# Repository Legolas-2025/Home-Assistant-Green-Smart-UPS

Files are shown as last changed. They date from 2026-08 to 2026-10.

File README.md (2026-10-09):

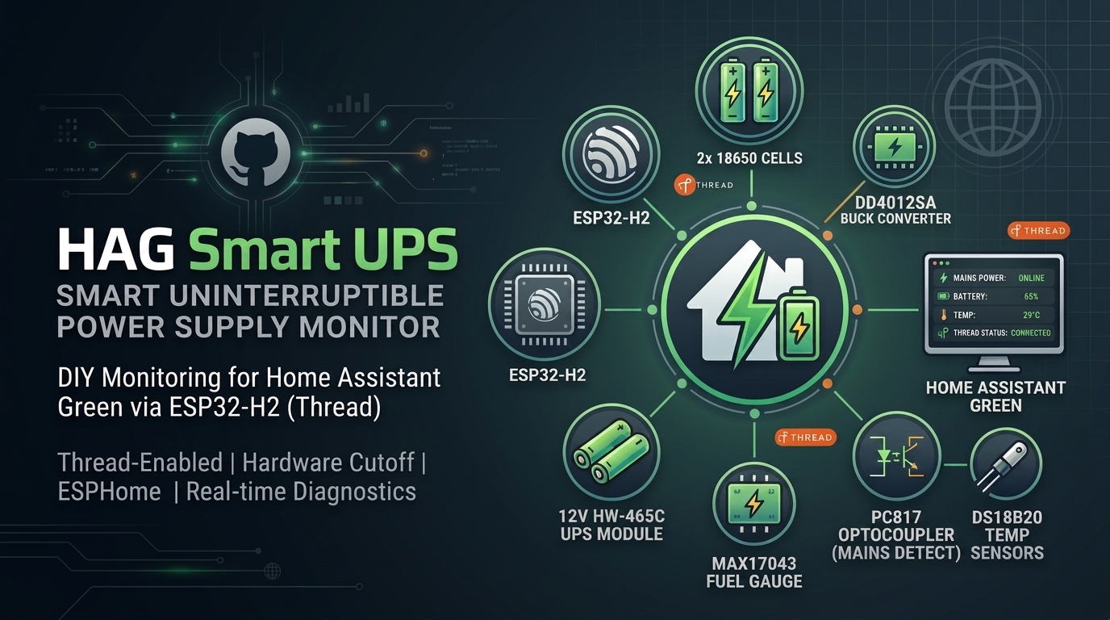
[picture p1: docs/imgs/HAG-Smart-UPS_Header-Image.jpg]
HAG Smart UPS


# Home Assistant Green Smart UPS - *Up To 5.5 Hours Runtime*

> A DIY Uninterruptible Power Supply with smart monitoring capabilities for the Home Assistant Green hub, featuring ESP32-H2 microcontroller and Thread wireless protocol.

## What's New in v1.2.1-alpha

**Changed — polling behaviour**
- **The Thread diagnostics were polling far faster than documented.** `openthread_info` defaults are aggressive:
  `parent_last_rssi` polls every **5 s**, and `role` / `ip_address` / `channel` every **1 s**. Those four
  entities alone accounted for roughly **11,500 messages per hour** over the Thread link — by a wide margin
  the largest source of traffic on this device, and far bigger than the sensor polling discussed below. They are
  now set to **900 s**.
- **The timestamp and status text sensors no longer self-poll.** They previously re-sent identical strings every
  60 s on top of being published explicitly by the mains-detection handlers. They now use
  `update_interval: never`, with the restored NVS values published once at boot.

**Added**
- **Delta filters on the battery and temperature sensors.** Readings are still taken on every poll but are only
  *transmitted* when they actually change — see [Sensor Update Intervals](#sensor-update-intervals).
- **`update_interval` now also governs both DS18B20 cell sensors**, so lowering the slider speeds up
  thermal-fault detection as well. Range widened from 10–120 s to **10–300 s**.

> Note when editing the YAML: `update_interval` must be placed **inside** each `openthread_info` entity key
> (`parent_last_rssi: { name: ..., update_interval: ... }`). At platform level it fails validation with
> `[update_interval] is an invalid option for [sensor.openthread_info]`.

---

## What's New in v1.2.0-alpha

> ⚠️ **Read this before upgrading from v1.1a** — your event timestamps were being recorded against the
> **wrong edge** of the mains-detection signal.

**Fixed**
- **Mains detection triggers were inverted.** The outage timestamp was written when power *arrived* and the
  restore timestamp when power *left*. Because the PC817 pulls GPIO4 LOW while mains is present and
  `inverted: true` maps LOW → ON, `on_press` is **mains restored** and `on_release` is **mains lost**.
  Both handlers are now swapped. This also resets the `low_bat_logged` flag at the correct moment, so the
  3 % critical event logs reliably on each subsequent outage.
- **Restore timestamps could be written as `1970-01-01`.** The mains-restored handler formatted the clock
  without checking `is_valid()`, so an unsynced clock produced a bogus epoch timestamp. It now reports
  `Time Sync Pending`, matching the outage handler.

**Added**
- **The *Sensor Update Interval* control now works.** It was declared but never read by any component — a
  dead entity advertised in the README. It now drives the MAX17043 polling loop at runtime and re-applies
  the stored value after a reboot.
- **`safe_mode` boot-loop guard**, tuned against the documented "Boot Loop on Power Restore" issue.
- Documented minimum ESPHome versions and the reason each one matters.

**Corrected in documentation** — runtime title now matches the 5–5.5 h calculation; the `tlv:` key is
documented as correct (see below); power pins are all on the top-right; the sample Thread dataset is now
valid hex; OVP removed from the DD4012SA protection list; "survives reboot" claims corrected.

> 🔒 **Do not "fix" `openthread: tlv:` into `network_dataset:`.** There is no such option — ESPHome fails
> to compile with `[network_dataset] is an invalid option for [openthread]`.

---

## Table of Contents
- [What's New in v1.2.1-alpha](#whats-new-in-v121-alpha)
- [What's New in v1.2.0-alpha](#whats-new-in-v120-alpha)
1. [Overview](#overview)
2. [Features](#features)
3. [Bill of Materials](#bill-of-materials)
4. [Power and Connection Diagram](#power-and-connection-diagram)
5. [Step-by-Step Assembly Guide](#step-by-step-assembly-guide)
6. [ESP32-H2 Super Mini Pinout Reference](#esp32-h2-super-mini-pinout-reference)
7. [Software Configuration](#software-configuration)
8. [Thread Network Setup](#thread-network-setup)
9. [Estimated Runtime](#estimated-runtime)
10. [Troubleshooting](#troubleshooting)
11. [Future Modifications](#future-modifications)

---

## Overview

This project provides a complete DIY Uninterruptible Power Supply (UPS) system with smart monitoring capabilities for the Home Assistant Green hub. The system utilizes:

- **ESP32-H2 Microcontroller**: Wireless communication via Thread protocol
- **HW-465C UPS Module**: 12V boost conversion and battery charging management
- **MAX17043 Fuel Gauge**: Real-time battery state of charge monitoring
- **DS18B20 Temperature Sensors**: Battery cell temperature monitoring
- **PC817 Optocoupler**: Mains power detection
- **DD4012SA Buck Converter**: 12V to 5V step-down conversion with built-in protections

The "Hardware Cutoff" configuration ensures the Home Assistant Green automatically reboots when grid power is restored, without requiring software-managed relays.

---

## Features

| Feature | Description |
|---|---|
| **Real-time Monitoring** | Battery level, voltage, cell temperatures, mains status |
| **Thread Protocol** | Wireless communication via OpenThread Border Router |
| **Persistent Logging** | NVS-backed timestamps that survive power loss |
| **Smart Time Sync** | Auto-retry mechanism (up to 4.5 minutes) |
| **Remote Management** | Restart button and adjustable polling interval |
| **Hardware Protection** | Automatic battery cutoff to prevent deep discharge |
| **Protected Power Path** | DD4012SA provides built-in UVLO/OCP/SCP/OTP for the ESP32 rail |

---

## Home Assistant Integration

Once flashed and connected to your Thread network, the HAG Smart UPS automatically integrates with Home Assistant, exposing a comprehensive set of entities for monitoring and control.

### Exposed Sensors

| Entity Name | Type | Description | Polled Every | Sent To HA When |
|---|---|---|---|---|
| **UPS Battery Level** | Percentage | Real-time state of charge from MAX17043 fuel gauge | 30s (slider 10-300s) | level moves ≥ 1 % |
| **UPS Battery Voltage** | Voltage (V) | Current battery voltage (3.0V - 4.2V range) | 30s (slider 10-300s) | moves ≥ 0.05 V |
| **UPS Battery Cell 1 Temperature** | Temperature (°C) | DS18B20 temperature reading on cell 1 | 30s (slider 10-300s) | moves ≥ 0.5 °C |
| **UPS Battery Cell 2 Temperature** | Temperature (°C) | DS18B20 temperature reading on cell 2 | 30s (slider 10-300s) | moves ≥ 0.5 °C |
| **UPS Thread Signal Strength** | RSSI (dBm) | Thread network signal strength to OTBR | 900s | every poll |

### Exposed Binary Sensors

| Entity Name | Type | Description |
|---|---|---|
| **Mains Power Status** | Binary | ON when grid power is present, OFF during outage |

### Exposed Text Sensors (Event Logging)

| Entity Name | Description | Persistence |
|---|---|---|
| **Time Sync** | Current time synchronization status (Pending/Success/Failed) | Resets on reboot |
| **Last Power Outage Time** | Timestamp when last mains failure was detected | Survives reboot |
| **Last Mains Restore Time** | Timestamp when mains power was restored | Survives reboot |
| **Last Low Battery 3% Time** | Timestamp when critical 3% battery threshold was reached during outage | Survives reboot |
| **Last Reboot Time** | Timestamp of last ESP32-H2 boot | Resets on reboot |

### Exposed Thread Network Info

| Entity Name | Description |
|---|---|
| **Thread Device Role** | Current OpenThread device role (Child/Sleepy End Device) |
| **Thread IP Address** | Assigned IPv6 address on the Thread network |
| **Thread Channel** | Thread radio channel in use |

### Exposed Buttons

| Entity Name | Action |
|---|---|
| **Restart UPS Monitor** | Triggers a soft restart of the ESP32-H2 firmware |

### Exposed Controls

| Entity Name | Range | Default | Description |
|---|---|---|---|
| **Sensor Update Interval** | 10s - 300s (10s steps) | 30s | Polling interval for the fuel gauge **and both cell temperature sensors** (live as of v1.2.0-alpha, extended in v1.2.1-alpha) |

---

## What You Get

Building this project gives you a complete, self-contained UPS monitoring solution for your Home Assistant Green hub:

**Core Functionality:**
- **Intelligent Battery Management**: The MAX17043 fuel gauge provides accurate state-of-charge readings, while the dual DS18B20 sensors monitor cell temperatures to prevent thermal runaway
- **Power Outage Detection**: Instant notification when mains power is lost, with automatic timestamp logging of outage start, end, and critical events
- **Automatic Recovery**: The "Hardware Cutoff" design ensures your Home Assistant Green reboots automatically when power is restored—no software intervention needed
- **Extended Runtime**: Up to 5.5 hours of backup power with dual 18650 cells in 1S2P configuration

**Smart Monitoring Features:**
- Persistent event logging that survives power cycles and reboots
- Smart time synchronization with automatic retry logic
- Configurable update intervals for battery polling
- Thread network diagnostics (signal strength, device role, IP address)

**Integration Benefits:**
- All entities appear automatically in Home Assistant via the native ESPHome API
- Build automations around power events (e.g., notify when outage begins, log battery levels)
- Remote device management with one-click restart capability
- No cloud dependencies—everything runs locally on your network

---

## Bill of Materials

### Core Components

| Component | Quantity | Notes |
|---|---|---|
| Home Assistant Green | 1 | Main hub (Load) |
| ESP32-H2 Super Mini | 1 | Thread end device |
| SLZB-MR5U (or similar) | 1 | OpenThread Border Router |
| HW-465C UPS Module | 1 | 12V boost + charger |
| 18650 Battery Cells | 2 | 3000mAh+ capacity, 1S2P configuration |
| MAX17043 I2C Fuel Gauge Module | 1 | Battery SoC monitoring |
| PC817 or EL817 Optocoupler | 1 | Mains detection (drop-in replacement — verify CTR if detection is unreliable) |
| DS18B20 Temperature Sensors | 2 | One per battery cell |
| DD4012SA Buck Converter (5V variant) | 1 | 12V to 5V conversion with built-in protections |

### Electronic Components

| Component | Value | Notes |
|---|---|---|
| Current-limiting Resistor (Optocoupler LED) | 330Ω | For optocoupler input |
| Pull-up Resistor (1-Wire Bus) | 4.7kΩ | For DS18B20 data line |
| Electrolytic Capacitor (Optional) | 100µF - 220µF | Voltage stabilization on the 5V rail |

### Power Supply Requirements

| Parameter | Specification | Notes |
|---|---|---|
| Input Voltage | 220V AC (Mains) | Standard household outlet |
| Output Voltage | 5V DC | USB-C connector |
| Output Current | 3.6A+ / 18W+ | Required for simultaneous charging and operation |
| Connector Type | USB-C | Must use "dumb" charger (no PD/PPS) |

> ⚠️ **IMPORTANT**: Do NOT use fast chargers with PD, PPS, or QuickCharge protocols. The HW-465C lacks smart negotiation chips, and these chargers will default to 5V/1A-2A, causing insufficient power supply.

### Cables and Connectors

| Item | Specification |
|---|---|
| DC Output Cable | 12V, male 5.5x2.1mm center-positive |
| Jumper Wires | Various lengths for prototyping |
| Breadboard/Prototype Board | For circuit assembly |

---

## DD4012SA Buck Converter - Detailed Specifications

The DD4012SA is a compact, industrial-grade 5W DC-DC step-down buck converter. The output voltage is **factory-set by SKU** (no potentiometer adjustment required), eliminating the risk of accidental over-voltage that can permanently damage the ESP32-H2.

### DD4012SA Configuration (5V Variant)

| Parameter | Value | Notes |
|---|---|---|
| Module Variant | DD4012SA_5V | Order specifically the 5V output version |
| Input Voltage | 6.5V – 40V DC | Range comfortably covers the 12V HW-465C rail |
| Output Voltage | 5.0V DC | Factory preset, no user adjustment required |
| Max Output Current | 1A | More than sufficient for the ESP32-H2 (~100 mA peak) |
| Quiescent Current | ~1.5 mA | Very low idle draw, battery-friendly |
| Efficiency | 76% – 90% | Depends on load and input voltage |
| Switching Frequency | 550 kHz | Fixed |
| Pin Pitch | 2.54 mm | Breadboard / Arduino-friendly |
| Form Factor | TO-220 compatible | Can drop-in replace LM78XX linear regulators |
| Dimensions | 18.4 × 10.3 × 6.6 mm | Ultra-compact |
| Operating Temperature | -40 °C to +85 °C | Industrial-grade |
| Power Rating | 5W | — |

### Built-in Protections (Major Advantage over Mini360)

| Protection | Description |
|---|---|
| **Overtemperature Shutdown (OTP)** | Module disables output if junction temperature exceeds safe limit |
| **Short Circuit Protection (SCP)** | Output shuts down on short circuit and auto-recovers when fault clears |
| **Input Under-Voltage Lockout (UVLO)** | Module disables output if input drops below minimum threshold |
| **Overcurrent Protection (OCP)** | Output current limited to safe value to protect module and load |
| **BS-Voltage Protection** | Internal bootstrap protection for the high-side switch |

> ✅ **No Potentiometer to Adjust**: Because the output voltage is factory-set per SKU, there is no risk of accidentally outputting 7V, 9V, or 12V to your ESP32-H2. Just order the **5V** variant (`DD4012SA_5V`) and connect it.

### DD4012SA Pinout

```
       ┌──────────────────┐
       │   DD4012SA 5V    │
       │  (Top View)      │
       │                  │
       │   ┌──────────┐   │
       │   │ IC +     │   │
       │   │ Inductor │   │
       │   └──────────┘   │
       │                  │
       └──┬─────┬─────┬───┘
          │     │     │
         IN+   GND   OUT+
        (VIN)  (GND) (VOUT)
       Pin 1  Pin 2  Pin 3
```

| Pin # | Label | Function | Connect To |
|---|---|---|---|
| 1 | **IN+** (VIN) | Power input (positive) | HW-465C **OUT+** (12V) |
| 2 | **GND** (IN-) | Power input (negative) / common ground | HW-465C **OUT-** |
| 3 | **OUT+** (VOUT) | 5V regulated output (positive) | ESP32-H2 **5V** pin |

> 📝 **Note**: The DD4012SA's 3-pin TO-220-style footprint is breadboard-friendly, so you can simply plug it into a breadboard or solder header pins for clean wiring. The **input** and **output** share the same **GND** reference (Pin 2).

### DD4012SA Wiring

- DD4012SA **IN+** (Pin 1) → HW-465C **OUT+** (12V)
- DD4012SA **GND** (Pin 2) → HW-465C **OUT-**
- DD4012SA **OUT+** (Pin 3, 5V) → ESP32-H2 **5V** pin (TOP RIGHT)
- ESP32-H2 **GND** pin (TOP RIGHT) → Common GND bus (DD4012SA GND, HW-465C OUT-)

> ⚠️ **NOTE**: The ESP32-H2 will be powered through the DD4012SA. When the HW-465C cuts off battery power, the ESP32 will also lose power, preventing deep discharge.

### Optional DD4012SA Output Stabilization

If the ESP32-H2 experiences boot loops when power is restored from a fully drained state, add a **100µF to 220µF electrolytic capacitor** across the DD4012SA 5V output (Pin 3) and GND (Pin 2).

---

## Power and Connection Diagram

### System Architecture Overview

```
                          ┌──────────────────┐
                          │    MAINS 220V    │
                          └─────────┬────────┘
                                    │ AC
                                    ▼
                          ┌──────────────────┐
                          │   5V USB-C PSU   │
                          │  (3.6A+ / 18W+)  │
                          └─────────┬────────┘
                                    │ 5V
                                    ▼
                          ┌──────────────────┐
                          │    HW-465C UPS   │
                          │  (12V Boost Core)│
                          │                  │
                          │ B+  B-  OUT+ OUT-│
                          └──┬───┬──────┬────┘
                             │   │      │     │ 5V rail
                             │   │      │     │ (via 330Ω)
                             │   │      │     ▼
                             │   │      │   ┌────────────────┐
                             │   │      │   │   PC817 LED    │
                             │   │      │   │ Pin1 ──► Pin2  │
                             │   │      │   └────────────────┘
                             │   │      │
                             │   │      └──────────► Home Assistant Green (12V Load)
                             │   │
                             │   └──────────────────┐
                             │                      │
                             ▼                      ▼
                      ┌─────────────┐         ┌─────────────┐
                      │   18650     │         │  DD4012SA   │
                      │   Pack      │         │  Buck Conv. │
                      │  (1S2P)     │         │  12V → 5V   │
                      │ ~6000 mAh   │         └──────┬──────┘
                      └──────┬──────┘                │ 5V
                             │                       ▼
                             │                ┌──────────────┐
                             │                │   ESP32-H2   │
                             │                │ Super Mini   │
                             │                └──┬────────┬──┘
                             │                   │        │
                             │                   │        │ Thread
                             │                   ▼        ▼
                             │            ┌──────────┐ ┌──────────┐
                             │            │ MAX17043 │ │SLZB-MR5U │
                             │            │  Fuel    │ │  (OTBR)  │
                             │            │  Gauge   │ └─────┬────┘
                             │            └────┬─────┘       │
                             │                 │             ▼
                             │                 │      ┌──────────────┐
                             │                 │      │ Home Asst    │
                             │                 │      │ Green (Load) │
                             │                 │      └──────────────┘
                             │                 │
                             ▼                 ▼
                        ┌────────────────────────┐
                        │     DS18B20 (x2)       │
                        │   Temperature Sensors  │
                        └────────────────────────┘
```

### Detailed Wiring Schematic

```
                               MAINS 220V
                                    │ AC
                                    ▼
                        ┌───────────────────────┐
                        │     5V USB-C PSU      │
                        │    (3.6A+ / 18W+)     │
                        └───────────┬───────────┘
                                    │ 5V (Red +, Black -)
                                    ▼
                        ┌───────────────────────┐
                        │       HW-465C UPS     │
                        │                       │
                        │  IN+  IN-  B+  B-     │
                        │  OUT+ OUT-            │
                        └──┬──┬──┬──┬──┬──┬─────┘
                           │  │  │  │  │  │
                           │  │  │  │  │  │
   ┌───────────────────────┘  │  │  │  │  └──────────────► Home Assistant Green
   │  (5V input rail for      │  │  │  │                   (12V Load)
   │   PC817 LED)             │  │  │  │
   │                          │  │  │  │
   ▼                          │  │  │  │
   ┌──────────┐               │  │  │  │
   │  330Ω    │               │  │  │  │
   │ Resistor │               │  │  │  │
   └────┬─────┘               │  │  │  │
        │                     │  │  │  │
        ▼                     │  │  │  │
   ┌────────────────┐         │  │  │  │
   │   PC817        │         │  │  │  │
   │  ┌────┐ ┌────┐ │         │  │  │  │
   │  │Pin1│ │Pin2│ │         │  │  │  │
   │  │(+) │ │(-) │ │         │  │  │  │
   │  └─┬──┘ └─┬──┘ │         │  │  │  │
   │    │      │    │         │  │  │  │
   │    │      └──────────────┘  │  │  │  (HW-465C GND)
   │    │                        │  │  │
   │    │                        │  │  │
   │    │  ┌────┐  ┌────┐        │  │  │
   │    │  │Pin4│  │Pin3│        │  │  │
   │    │  │(C) │  │(E) │        │  │  │
   │    │  └─┬──┘  └─┬──┘        │  │  │
   └────┼────┼───────┼───────────┘  │  │  │
        │    │       │              │  │  │
        │    │       └──────────────┘  │  │  (GND bus)
        │    │                         │  │
        │    │                         │  │
        ▼    │                         │  │
   ESP32-H2  │                         │  │
   GPIO 4    │                         │  │
   (Mains)   │                         │  │
             │                         │  │
             │                         │  └──────► DD4012SA GND (Pin 2)
             │                         │
             │                         └─────────► DD4012SA IN+ (Pin 1)  [12V]
             │
             │  (Battery path)
             │
             ▼
       ┌───────────┐
       │  18650    │
       │   Pack    │
       │  (1S2P)   │
       │ ~6000 mAh │
       │ B+     B- │
       └──┬────┬───┘
          │    │
          │    └──────────────────────────► GND bus (common)
          │
          └─── CELL+ sense ───────────────► MAX17043 CELL+ (battery sense)
```

#### ESP32-H2 Wiring Detail

```
                       ┌───────────────────┐
                       │   DD4012SA        │
                       │  ┌───┐┌───┐┌────┐ │
                       │  │IN+││GND││OUT+│ │
                       │  │   ││   ││    │ │
                       │  └─┬─┘└─┬─┘└─┬──┘ │
                       └────┼────┼────┼────┘
                            │    │    │
                           12V  GND  5V
                            │    │    │
                            │    │    └──────► ESP32-H2 5V  (TOP RIGHT)
                            │    │
                            │    └───────────► ESP32-H2 GND (TOP RIGHT, common GND bus)
                            │
                            └───── (from HW-465C OUT+)

                       ┌─────────────────────────┐
                       │      ESP32-H2           │
                       │      Super Mini         │
                       │                         │
                       │  ┌────┐         ┌────┐  │
                       │  │ 5V │         │GND │  │
                       │  └────┘         └────┘  │
                       │  ┌────┐         ┌────┐  │
                       │  │3V3 │         │GPIO│  │
                       │  └────┘         │ 10 │◄─┼── MAX17043 SDA
                       │  ┌────┐         └────┘  │
                       │  │GPIO│         ┌────┐  │
                       │  │ 11 │◄────────│GPIO│  │
                       │  └────┘  MAX    │ 5  │◄─┼── DS18B20 Data
                       │          SCL    └─┬──┘  │
                       │                   │     │
                       │  ┌────┐           │ ┌───┴───────────┐
                       │  │GPIO│           └►│ 4.7kΩ Pull-up │
                       │  │ 4  │◄─── PC817   │   (to 3V3)    │
                       │  └────┘    Pin 4    └───────────────┘
                       └─────────────────────────┘
```

#### Sensor Wiring Detail

```
                            ┌──────────────────┐
                            │   18650 Pack     │
                            │  ┌───┐    ┌───┐  │
                            │  │C1 │    │C2 │  │
                            │  │+ -│    │+ -│  │
                            │  └─┬─┘    └─┬─┘  │
                            │    │        │    │
                            │    └───┬────┘    │
                            │        │         │
                            │   B+   │   B-    │
                            └────┬───┴────┬────┘
                                 │        │
                                 ▼        ▼
                            (to HW-465C B+ and B-)

   ┌─────────────────────┐                ┌─────────────────────┐
   │     MAX17043        │                │     DS18B20 x2      │
   │    Fuel Gauge       │                │   Temp Sensors      │
   │                     │                │                     │
   │  ┌────┐  ┌────┐     │                │  ┌────┐    ┌────┐   │
   │  │ VCC│  │ GND│     │                │  │ VCC│    │ VCC│   │
   │  └─┬──┘  └─┬──┘     │                │  └─┬──┘    └─┬──┘   │
   │    │       │        │                │    │         │      │
   │    │       │        │                │   3V3       3V3     │
   │  ┌────┐  ┌────┐     │                │    │         │      │
   │  │ SDA│  │ SCL│     │                │    ├─────────┤      │
   │  └─┬──┘  └─┬──┘     │                │    │         │      │
   │    │       │        │                │  ┌────┐   ┌────┐    │
   │  ┌──────┐  │        │                │  │ DQ │   │ DQ │    │
   │  │CELL+ │  │        │                │  └─┬──┘   └─┬──┘    │
   │  └──┬───┘  │        │                │    │         │      │
   │     │      │        │                │    ├─────────┤      │
   │     │      │        │                │    │         │      │
   └─────┼──────┼────────┘                │   GND       GND     │
         │      │                         │    │         │      │
         │      │                         │    └────┬────┘      │
         │      │                         │         │           │
         │      │                         │   ┌─────┴─────┐     │
         │      │                         │   │  4.7kΩ    │     │
         │      │                         │   │  Pull-up  │     │
         │      │                         │   │  (to 3V3) │     │
         │      │                         │   └─────┬─────┘     │
         │      │                         └─────────┼───────────┘
         │      │                                   │
         │      │                                   ▼
         │      │                           ESP32-H2 GPIO 5
         │      │                           (1-Wire Data)
         │      │
         ▼      ▼
   ESP32 3V3   ESP32 GND
   (3V3 rail)  (GND bus)

         │
         ▼
   Battery B+  (direct, NOT 12V rail)

   ┌─────────────────────────┐
   │   MAX17043 Connections  │
   │                         │
   │  VCC   ──► ESP32 3V3    │
   │  GND   ──► ESP32 GND    │
   │  SDA   ──► ESP32 GPIO 10│
   │  SCL   ──► ESP32 GPIO 11│
   │  CELL+ ──► Battery B+   │
   │            (direct!)    │
   └─────────────────────────┘
```

#### Mains Detection Wiring (PC817 Optocoupler)

```
   HW-465C 5V rail
        │
        ▼
   ┌─────────┐
   │  330Ω   │
   │ Resistor│
   └────┬────┘
        │
        ▼
   ┌────────────────────────────────┐
   │            PC817               │
   │                                │
   │  INPUT (LED side)              │
   │  ┌──────────┐   ┌──────────┐   │
   │  │  Pin 1   │   │  Pin 2   │   │
   │  │  Anode + │   │ Cathode -│   │
   │  └────┬─────┘   └────┬─────┘   │
   │       │              │         │
   │       │              └────► HW-465C GND
   │       │
   │       └──── from 330Ω resistor
   │
   │  OUTPUT (Transistor side)      │
   │  ┌──────────┐   ┌──────────┐   │
   │  │  Pin 4   │   │  Pin 3   │   │
   │  │ Collector│   │ Emitter  │   │
   │  └────┬─────┘   └────┬─────┘   │
   │       │              │         │
   │       │              └───────► ESP32-H2 GND (common)
   │       │
   │       └─────────────► ESP32-H2 GPIO 4 (mains detection input)
   └────────────────────────────────┘

   Logic:
   ┌──────────────┬──────────┬──────────────┬──────────┐
   │ Mains Status │ LED State│ Transistor   │ GPIO 4   │
   ├──────────────┼──────────┼──────────────┼──────────┤
   │ Present      │ ON       │ Conducting   │ LOW      │
   │ Lost         │ OFF      │ Off          │ HIGH     │
   └──────────────┴──────────┴──────────────┴──────────┘
```

---

## Step-by-Step Assembly Guide

### Phase 1: Preparation and Safety

> ⚠️ **Safety Warning**: Always work with batteries in a well-ventilated area. Never short-circuit battery terminals. Handle with care to prevent damage.

#### Step 1.1: Gather All Components
Before starting, ensure you have all the components listed in the [Bill of Materials](#bill-of-materials).

#### Step 1.2: Prepare Your Workspace
1. Clear a clean, static-free workspace
2. Have insulating materials available (rubber mat, foam)
3. Keep metal tools away from battery terminals
4. Prepare a fire extinguisher (Class D for lithium)

---

### Phase 2: Prepare the DD4012SA Buck Converter

> ✅ **EASIER THAN Mini360**: The DD4012SA ships with the output voltage factory-set. **There is no potentiometer to adjust** — order the **5V variant** (often listed as `DD4012SA_5V` or "Output: 5V") and you are done. This eliminates the entire "adjust-pot-while-measuring-with-multimeter" step required by the Mini360.

#### Step 2.1: Verify You Have the Correct Variant
1. **Check the listing/SKU** you ordered: it must be the **5V output** variant of the DD4012SA
2. **Inspect the module**: most DD4012SA boards have the output voltage printed on the top of the IC or silkscreened near the inductor
3. Common SKUs:
   - `DD4012SA_3V3` → 3.3V output ❌ (wrong for this project)
   - `DD4012SA_5V` → 5V output ✅ (correct)
   - `DD4012SA_12V` → 12V output ❌ (wrong for this project)

#### Step 2.2: Bench-Verify Output (Recommended but Optional)

Because the DD4012SA has built-in protections, you can safely bench-test before connecting to the ESP32-H2.

DD4012SA Configuration:
├── Variant: 5V (factory preset — no user adjustment)
├── Input Voltage: 6.5V – 40V DC (12V from HW-465C is in range)
├── Output Voltage: 5.0V DC
├── Max Output Current: 1A
├── Quiescent Current: ~1.5 mA
├── Efficiency: 76% – 90%
└── Protections: OTP, OCP, SCP, UVLO, BS-voltage

**Bench test (optional, 1 minute):**
1. Connect a 9V–12V DC source to **IN+** (Pin 1) and **GND** (Pin 2)
2. Measure the voltage on **OUT+** (Pin 3) with a multimeter
3. It should read **5.0V ± 0.1V** — if not, you have the wrong variant
4. Disconnect the test supply

---

### Phase 3: Assemble the Battery Pack (1S2P)

#### Step 3.1: Prepare Battery Cells
1. Identify two 18650 battery cells (recommended: 3000mAh+ each)
2. **Check voltage** of each cell with a multimeter:
   - Acceptable range: 3.6V - 4.2V
   - Reject cells below 3.0V

#### Step 3.2: Wire in Parallel

```
Battery Pack Wiring (1S2P):
┌─────────────────────────┐
│   Parallel Bus (+)      │◄── Solder B+ from both cells here
└─────────────────────────┘
        │                │
  ┌─────┴─┐         ┌────┴─────┐
  │ Cell 1│         │  Cell 2  │
  │  B+   │         │   B+     │
  └───────┘         └──────────┘
        │                │
  ┌─────┴─┐         ┌────┴─────┐
  │ Cell 1│         │  Cell 2  │
  │  B-   │         │   B-     │
  └───────┘         └──────────┘
        │                │
┌─────────────────────────┐
│   Parallel Bus (-)      │◄── Solder B- from both cells here
└─────────────────────────┘
Output: 3.7V nominal, ~6000mAh total capacity
```

#### Step 3.3: Connect to HW-465C
1. **Solder** the positive bus to **B+** terminal on HW-465C
2. **Solder** the negative bus to **B-** terminal on HW-465C
3. **Use heat-shrink tubing** to insulate connections

---

### Phase 4: Wire the Power Supply Path

#### Step 4.1: Connect USB-C PSU to HW-465C
1. **Cut** the USB-C cable from the power supply
2. **Strip** the wires (typically Red = +, Black = -)
3. **Solder** Red to **IN+** terminal
4. **Solder** Black to **IN-** terminal

#### Step 4.2: Connect HW-465C 12V Output
1. **Prepare** a 12V DC output cable with male 5.5x2.1mm connector
2. **Connect** the cable to **OUT+** and **OUT-** terminals
3. **This cable** will power both the Home Assistant Green AND the DD4012SA

#### Step 4.3: Wire the DD4012SA Buck Converter
1. **Connect** DD4012SA **IN+** (Pin 1) to HW-465C **OUT+** (12V)
2. **Connect** DD4012SA **GND** (Pin 2) to HW-465C **OUT-**
3. **Verify** polarity before applying power

#### Step 4.4: Connect DD4012SA to ESP32-H2
1. **Connect** DD4012SA **OUT+** (Pin 3, 5V) to ESP32-H2 **5V** pin (TOP RIGHT)
2. **Connect** ESP32-H2 **GND** pin (TOP RIGHT) to the common GND bus (DD4012SA Pin 2)

> ⚠️ **NOTE**: The ESP32-H2 will be powered through the DD4012SA. When the HW-465C cuts off battery power, the ESP32 will also lose power, preventing deep discharge.

---

### Phase 5: Wire the MAX17043 Fuel Gauge

#### Step 5.1: Power Connections

| MAX17043 Pin | ESP32-H2 Pin | Wire Color |
|---|---|---|
| VCC (3V3) | 3V3 (TOP RIGHT) | Yellow |
| GND | GND | Black |
| SDA | GPIO 10 (RIGHT SIDE) | Green |
| SCL | GPIO 11 (RIGHT SIDE) | Blue |

#### Step 5.2: Critical - Battery Sense Connection

> ⚠️ **CRITICAL CONNECTION**: This must be connected correctly to avoid damage and ensure accurate readings.

1. **Locate** the CELL+ or VIN pin on the MAX17043 module
2. **Connect directly** to the **battery pack positive terminal (B+)** on the HW-465C
3. **DO NOT** connect to 12V output or 5V rail
4. **This pin** monitors raw battery voltage (3.0V - 4.2V)

MAX17043 Wiring Diagram:
```
┌─────────────────┐
│   MAX17043      │
│   Fuel Gauge    │
│                 │
│  ┌────┐  ┌────┐ │
│  │VCC │  │GND │ │
│  └─┬──┘  └─┬──┘ │
│    │       │    │
│  ┌────┐  ┌────┐ │
│  │SDA │  │SCL │ │
│  └─┬──┘  └─┬──┘ │
│    │       │    │
│  ┌───────────┐  │
│  │  CELL+    │──┼──► Battery B+ (Direct!)
│  │  (Sense)  │  │   DO NOT connect to 12V
│  └───────────┘  │
└─────────────────┘
```

---

### Phase 6: Wire the DS18B20 Temperature Sensors

#### Step 6.1: Sensor Placement
1. **Prepare** two DS18B20 temperature sensors with wires
2. **Attach** sensor 1 directly to Cell 1 using thermal tape or heat-shrink
3. **Attach** sensor 2 directly to Cell 2 using thermal tape or heat-shrink
4. **Position** sensors for good thermal contact with the battery metal casing

#### Step 6.2: Wiring (Both Sensors Share One GPIO)

```
DS18B20 Wiring (Daisy-chained):

ESP32-H2                DS18B20 #1                DS18B20 #2
┌────────────┐         ┌──────────────┐          ┌──────────────┐
│   3V3      │─────────│    VCC       │──────────│    VCC       │
│            │         │              │          │              │
│   GPIO 5   │────┬────│    Data      │─────┬────│    Data      │
│            │    │    │              │     │    │              │
│   GND      │────│────│    GND       │─────┼────│    GND       │
│            │    │    └──────────────┘     │    └──────────────┘
│            │    │                         │
│            │    └─────┐ ┌──────────┐
│            │          │ │ 4.7kΩ    │
│            │          │ │ Pull-up  │
│            │          │ │ (to 3V3) │
│            │          │ └────┬─────┘
└────────────┘          └──────┘
```

#### Step 6.3: Install Pull-up Resistor
1. **Connect** a **4.7kΩ resistor** between GPIO 5 and 3.3V on the ESP32-H2
2. This is **essential** for reliable 1-Wire communication

---

### Phase 7: Wire the PC817 Optocoupler (Mains Detection)

#### Step 7.1: Understanding the Circuit
The optocoupler provides **galvanic isolation** between the mains detection circuit and the ESP32. When mains power is present, the LED inside the optocoupler lights up, causing the transistor to conduct and pull GPIO 4 LOW.

#### Step 7.2: Input Side (LED) Connections

```
Optocoupler Input (Mains Detection):

HW-465C 5V Rail                              PC817
      │                                       │
      │   ┌──────────────┐                    │
      │   │   330Ω       │                    │
      │   │  Resistor    │                    │
      │   └──────┬───────┘                    │
      │          │                            │
      └──────────┼───────────────────────────►│ Pin 1 (+)
      │                                       │ Pin 2 (-)
      └───────────────────────────────────────┘
                                              │
                                         HW-465C GND
```

1. **Connect** 5V from HW-465C to one side of 330Ω resistor
2. **Connect** other side of resistor to **Pin 1** (Anode +) of PC817
3. **Connect** Pin 2 (Cathode -) to HW-465C GND

#### Step 7.3: Output Side (Transistor) Connections

| PC817 Pin | ESP32-H2 Pin | Function |
|---|---|---|
| Pin 4 (Collector) | GPIO 4 (LEFT SIDE) | Pulled LOW when mains present |
| Pin 3 (Emitter) | GND | Common ground |

#### Step 7.4: Logic Summary

| Mains Status | LED State | Transistor | GPIO 4 | Home Assistant |
|---|---|---|---|---|
| Present | ON | Conducting | LOW | ON |
| Lost | OFF | Off | HIGH | OFF |

---

### Phase 8: Final Assembly

#### Step 8.1: Verify All Connections
Before powering on, double-check:
- [ ] DD4012SA is the **5V** variant (factory-set, no adjustment needed)
- [ ] Battery pack wired correctly (1S2P)
- [ ] MAX17043 CELL+ connected to battery B+ (NOT 12V rail)
- [ ] PC817 330Ω resistor in place
- [ ] 4.7kΩ pull-up on DS18B20 data line
- [ ] All GND connections shared properly
- [ ] No exposed wires touching

#### Step 8.2: Initial Power-Up Test
1. **Connect** USB-C power supply to HW-465C
2. **Verify** 12V output with multimeter
3. **Verify** DD4012SA output is 5.0V (NOT higher!)
4. **Check** ESP32-H2 for power indication
5. **Monitor** for any heat from components

#### Step 8.3: Optional - Add Stabilization Capacitor
If the ESP32-H2 experiences boot loops when power is restored from a fully drained state, add a **100µF to 220µF electrolytic capacitor** across the DD4012SA 5V output (Pin 3) and GND (Pin 2).

---

## ESP32-H2 Super Mini Pinout Reference

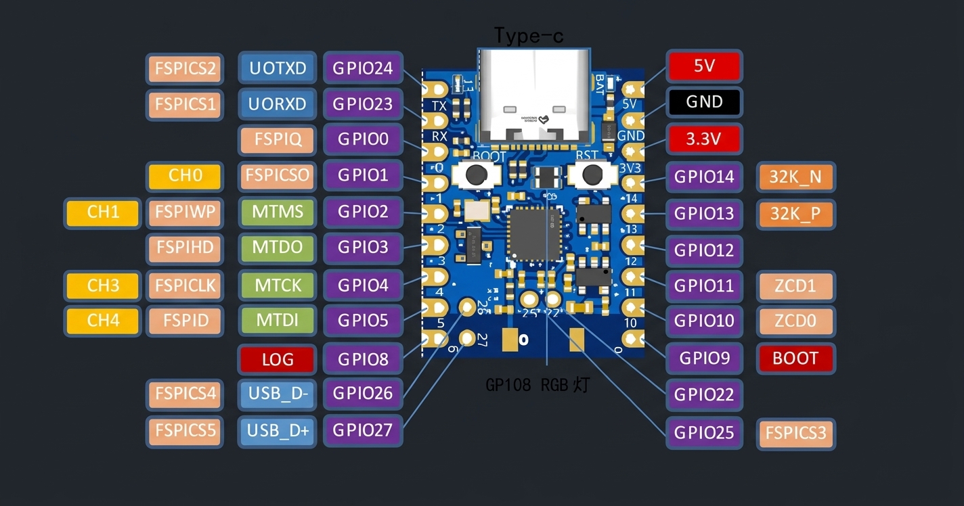
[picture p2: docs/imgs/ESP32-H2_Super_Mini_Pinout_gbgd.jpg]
ESP32-H2 Super Mini Pinout


> ⚠️ **Board-Specific Pinout**: This pinout matches the ESP32-H2 Super Mini board with **vertical layout** (22-pin version as shown in your photo). Your board may differ from generic ESP32-H2 pinouts.

### Complete Pin Assignment Table

| Pin Label | GPIO | Alternate Functions | Connected To | Notes |
|---|---|---|---|---|
| 5V | — | Power Input | DD4012SA OUT+ (5V) | Main power input (TOP RIGHT) |
| GND | — | Ground | DD4012SA GND, PC817 Pin 3 | Common ground (TOP RIGHT) |
| 3V3 | — | 3.3V Output | MAX17043 VCC, DS18B20 VCC | Sensor power rail (TOP RIGHT) |
| GPIO 4 | 4 | JTAG(MTCK), ADC_CH3 | PC817 Pin 4 | Mains Detection (LEFT SIDE) |
| GPIO 5 | 5 | JTAG(MTDI), ADC_CH4 | DS18B20 Data | 1-Wire bus, needs 4.7kΩ pull-up (LEFT SIDE) |
| GPIO 10 | 10 | ZCD0, SPI | MAX17043 SDA | I2C Data (RIGHT SIDE) ⚠️ |
| GPIO 11 | 11 | ZCD1, SPI | MAX17043 SCL | I2C Clock (RIGHT SIDE) ⚠️ |

### Visual Pinout (Your Board Layout)

```
┌─────────────────────────────────┐
│  ESP32-H2 Super Mini            │
│  (Vertical)                     │
└─────────────────────────────────┘
═══════════════════════════════════════════════════════════════════
│
LEFT SIDE ◄── ────► RIGHT SIDE   (5V / GND / 3V3 header sits at TOP RIGHT)
┌──────┐
│  TX  │ ◄── GPIO24 (NC)
├──────┤
│  RX  │ ◄── GPIO23 (NC)
├──────┤
│  0   │ ◄── GPIO0  (NC)
├──────┤
│  1   │ ◄── GPIO1  (NC)
├──────┤
│  2   │ ◄── GPIO2  (NC)
├──────┤
│  3   │ ◄── GPIO3  (NC)
├──────┤
│  4   │ ◄── GPIO4  ⚡ MAINS DETECTION
├──────┤
│  5   │ ◄── GPIO5  🌡️ 1-WIRE / DS18B20
├──────┤
│  8*  │ ◄── GPIO8  RGB LED (DO NOT USE)
├──────┤
│  26  │ ◄── GPIO26 USB_D- (NC)
├──────┤
│  27  │ ◄── GPIO27 USB_D+ (NC)
└──────┘
RIGHT SIDE
┌──────┐
│  5V  │ ◄── Power Input (5V in, TOP RIGHT)
├──────┤
│ GND  │ ◄── Ground
├──────┤
│  3V3 │ ◄── 3.3V output (sensor rail)
├──────┤
│  14  │ ◄── GPIO14 32K (NC)
├──────┤
│  13  │ ◄── GPIO13 32K (NC)
├──────┤
│  12  │ ◄── GPIO12 (NC)
├──────┤
│  11  │ ◄── GPIO11 🔌 I2C SCL
├──────┤
│  10  │ ◄── GPIO10 🔌 I2C SDA
├──────┤
│  9*  │ ◄── GPIO9  BOOT (NC)
├──────┤
│  22  │ ◄── GPIO22 (NC)
├──────┤
│  25  │ ◄── GPIO25 (NC)
└──────┘
═══════════════════════════════════════════════════════════════════
```

### Pin Connections Summary for Your Board

```
╔══════════════════════════════════════════════════════════════════════╗
║  YOUR ESP32-H2 SUPER MINI - CONNECTIONS                              ║
╠══════════════════════════════════════════════════════════════════════╣
║                                                                      ║
║  POWER CONNECTIONS:                                                  ║
║  ┌─────────────────────────────────────────────────────────────┐     ║
║  │ DD4012SA OUT+ (5V) ──────────────► 5V pin (TOP RIGHT)        │     ║
║  │ DD4012SA GND  ──────────────► GND pin (TOP RIGHT)            │     ║
║  │ MAX17043 VCC ──────────────► 3V3 pin (TOP RIGHT)            │     ║
║  └─────────────────────────────────────────────────────────────┘     ║
║                                                                      ║
║  I2C CONNECTIONS (MAX17043 Fuel Gauge):                              ║
║  ┌─────────────────────────────────────────────────────────────┐     ║
║  │ MAX17043 GND ──────────────► GND pin                        │     ║
║  │ MAX17043 SDA ──────────────► GPIO 10 (RIGHT SIDE) ⚠️       │     ║
║  │ MAX17043 SCL ──────────────► GPIO 11 (RIGHT SIDE) ⚠️       │     ║
║  │ MAX17043 CELL+ ─────────────► Battery B+ (Direct!)          │     ║
║  └─────────────────────────────────────────────────────────────┘     ║
║                                                                      ║
║  1-WIRE CONNECTIONS (DS18B20 Temperature):                           ║
║  ┌─────────────────────────────────────────────────────────────┐     ║
║  │ DS18B20 VCC ──────────────► 3V3 pin                         │     ║
║  │ DS18B20 GND ──────────────► GND pin                         │     ║
║  │ DS18B20 DATA ──────────────► GPIO 5 (LEFT SIDE)             │     ║
║  │ DS18B20 + 4.7kΩ pull-up ───► 3V3 pin                        │     ║
║  └─────────────────────────────────────────────────────────────┘     ║
║                                                                      ║
║  MAINS DETECTION (PC817 Optocoupler):                                ║
║  ┌─────────────────────────────────────────────────────────────┐     ║
║  │ PC817 Pin 4 (Collector) ─────► GPIO 4 (LEFT SIDE)           │     ║
║  │ PC817 Pin 3 (Emitter)  ─────► GND pin                       │     ║
║  └─────────────────────────────────────────────────────────────┘     ║
║                                                                      ║
╚══════════════════════════════════════════════════════════════════════╝

Legend:
⚡ = Mains Detection (GPIO4) - LEFT side
🌡️ = 1-Wire DS18B20 (GPIO5) - LEFT side
🔌 = I2C MAX17043 (GPIO10=SDA, GPIO11=SCL) - RIGHT side
⚠️ = Despite ZCD label, still supports I2C functionality
```

### Important Board-Specific Notes

> ⚠️ **Board Differences**: Your ESP32-H2 Super Mini board (22-pin vertical layout) has several differences from generic ESP32-H2 documentation:

1. **GPIO10/GPIO11 are labeled ZCD0/ZCD1** (Zero Cross Detection)
   - Despite the ZCD labeling, these pins **still support I2C functionality**
   - The original YAML configuration using these pins for I2C is **correct** ✓
2. **Native USB on GPIO26/GPIO27**
   - This board uses the ESP32-H2's native USB controller
   - No external USB-UART chip (CP2102) needed
   - GPIO26 = USB_D-, GPIO27 = USB_D+
3. **Internal RGB LED on GPIO8**
   - GPIO8 is hard-wired to the onboard RGB LED
   - **DO NOT use GPIO8 for external components**
4. **BOOT Pin on GPIO9**
   - GPIO9 is a strapping pin
   - Pulled low by the BOOT button during reset
   - Avoid using for critical inputs
5. **Power Pin Locations**
   - **5V, GND and 3V3 are all on the TOP RIGHT**, stacked contiguously as a single 3-pin header
   - There is **no power pin on the left side** — the left column starts at `TX` (GPIO24)
   - The board has a **vertical orientation**
   - A `BAT` pad is present next to the 5V pin (battery input); it is unused in this build

---

## Software Configuration

### ESPHome YAML Configuration
The complete ESPHome configuration is available in [`hag_smart_ups.yaml`](hag_smart_ups.yaml) (shipped with this release, **v1.2.1-alpha**).

#### Requirements

| Component | Minimum Version | Why |
|---|---|-----|
| ESPHome | **2026.9.1** (validated against) | Uses `openthread_info` sensor/text_sensor platforms and `number` template `set_action` |
| ESPHome | 2025.11.0 | `dallas_temp` gained the `index:` option (removed in 2024.6, restored in 2025.11) |
| ESPHome | 2025.6.0 | `openthread` component introduced |
| Thread border router | OTBR (e.g. SLZB-MR5U) | No Wi-Fi on the ESP32-H2 |

> ⚠️ **Do not change `tlv:` to `network_dataset:`.** The `openthread` component's dataset key is `tlv`
> (`CONF_TLV` in `esphome/components/openthread/const.py`). `network_dataset` is **not a valid option** and
> ESPHome will refuse to compile with
> `[network_dataset] is an invalid option for [openthread]`. The value is a **hex-encoded operational
> dataset TLV**, not a file path.

### Key Configuration Sections
```yaml
# Thread Protocol Configuration
openthread:
  device_type: MTD  # Minimal Thread Device (battery optimized)
  tlv: !secret my_thread_dataset   # hex TLV - NOT a filename

# Thread is IPv6-only; enable_ipv6 is NOT set automatically
network:
  enable_ipv6: true

# Boot-loop guard (top-level component, not an ota: platform)
safe_mode:
  boot_is_good_after: 2min
  num_attempts: 10
  reboot_timeout: 5min

# MAX17043 I2C Configuration
# Pins must be explicit: ESPHome's built-in SDA/SCL aliases resolve to
# GPIO21/GPIO22 on every ESP32 variant, and GPIO21 is a SPI-flash pin on H2.
i2c:
  sda: GPIO10
  scl: GPIO11
  scan: true

# DS18B20 1-Wire Configuration
one_wire:
  - platform: gpio
    pin: GPIO5

# Mains Detection (GPIO4, inverted)
# The PC817 collector pulls GPIO4 LOW while mains is present, so
# inverted:true makes LOW -> state true. Therefore:
#   on_press   (state -> true)  = mains RESTORED
#   on_release (state -> false) = mains LOST
binary_sensor:
  - platform: gpio
    pin:
      number: GPIO4
      inverted: true
```

### Sensor Update Intervals

| Sensor | Interval | Configurable Range | Transmits On |
|---|---|---|---|
| Battery Level (MAX17043) | 30s | 10s - 300s (via the *Sensor Update Interval* number) | ≥ 1 % change |
| Battery Voltage (MAX17043) | 30s | shared — same slider | ≥ 0.05 V change |
| Temperature (DS18B20) ×2 | 30s | shared — same slider | ≥ 0.5 °C change |
| Thread Signal (RSSI) | 900s | Fixed | every poll |
| Thread role / IP / channel | 900s | Fixed | every poll |
| Timestamp + status text sensors | never | n/a | on event, plus once at boot |

> The *Sensor Update Interval* number entity was inert in v1.1a — it was declared but never read by any
> component. As of **v1.2.0-alpha** it drives `set_update_interval()` on the MAX17043 polling loop, and the
> stored value is re-applied on boot. As of **v1.2.1-alpha** it also governs **both DS18B20 cell sensors**,
> so lowering it speeds up thermal-fault detection too. Range widened to 10s - 300s.

#### Why the cell temperatures are polled fast

The DS18B20 cadence is tied to the slider rather than slowed, deliberately. An 18650 has roughly 40 J/K of
thermal capacity, so a developing internal fault raises its temperature quickly — about **15 °C/min at 10 W**,
or **30 °C/min at 20 W**. A 300 s sampling interval would therefore miss most of the event: at 10 W the cell
gains ~75 °C between two samples, i.e. from a 25 °C starting point it would be at 100 °C before it was even
reported.

The cost of that fast cadence is kept near zero by the delta filters rather than by slowing the reads. The
sensor is still **read** on every poll (a local 1-Wire transaction — cheap), but the value is only sent when
it has actually moved, so normal thermal drift produces almost no network traffic while a genuine event still
surfaces within one poll of onset.

#### Delta filters: reading fast, transmitting rarely

ESPHome publishes a sensor's state on **every** poll, even when the value is byte-for-byte identical to the
last one — `force_update` only affects whether Home Assistant records the value in its database, not whether
the message crosses the network. This release adds `filters:` thresholds so unchanged readings are dropped
before transmission:

| Entity | Filter |
|---|---|
| Cell temperature ×2 | `delta: 0.5` (°C) |
| Battery level | `delta: 1` (%) |
| Battery voltage | `delta: 0.05` (V) |

The 3 % critical-battery check deliberately uses `on_raw_value` rather than `on_value`, so it is evaluated on
**every** reading even when the filter suppresses the network send.

### DS18B20 Addressing

`index:` is **0-based** and follows the sensors' ROM-code probe order, so cell 1 / cell 2 can swap if you
re-pick or re-order the sensors. ESPHome prints each sensor's unique hex address on first boot; switch both
entries to `address:` once you have recorded them:

```yaml
- platform: dallas_temp
  address: 0x1234567890ABCD01   # mutually exclusive with index:
```

### Time Synchronization
The system includes a smart time sync mechanism:
- **Initial sync**: Upon boot
- **Retry interval**: Every 30 seconds
- **Max retries**: 9 attempts (~4.5 minutes)
- **Status states**: `Pending...`, `Success`, `Failed - try to restart`

---

## Thread Network Setup

### Prerequisites
1. **OpenThread Border Router** (OTBR) must be operational
   - SLZB-MR5U (recommended)
   - Raspberry Pi with OTBR software
   - Other compatible OTBR hardware
2. **Thread Network Dataset**
   - Obtain from your OTBR
   - Store securely in `secrets.yaml`

### Configuration
Add the following to your `secrets.yaml`:

```yaml
# Your Thread network dataset (from OTBR) — a hex-encoded operational dataset TLV.
# It must be a single unbroken hex string with an EVEN number of characters.
# ESPHome rejects it otherwise with: "TLV must have an even number of hex characters."
# The value below is an ILLUSTRATIVE placeholder — replace it with your own dataset.
my_thread_dataset: "0002000B0102123402080011223344556677031000112233445566778899AABBCCDDEEFF040F4F70656E5468726561642D44656D6F050800112233445566770710FD000DB80000000000000000000000010800090200000A0200000B0200000C080011223344556677350400040000"

# ESPHome API encryption key — 32-byte base64 value.
# Generate one with:  python3 -c "import base64,os;print(base64.b64encode(os.urandom(32)).decode())"
hag_ups_monitor__encryption_key: "your_encryption_key_here"
```

> ⚠️ **Do not paste prose into the dataset.** Inline comments, "(This is an example…)" notes or line-wrapped
> blocks are all rejected by the hex validator. Keep it as one quoted line of pure hex.

### Thread Device Role
The ESP32-H2 is configured as an **MTD (Minimal Thread Device)**:
- Sleepy end device behavior
- Battery optimized
- Parent: OTBR (SLZB-MR5U)
- Role: Child/End Device

---

## Estimated Runtime

### Calculation Basis

| Parameter | Value | Notes |
|---|---|---|
| HAG Power (idle) | ~3W | Average idle/low-load |
| ESP32-H2 Power | ~0.1W | MTD average |
| System Total | ~3.1W | Combined load |
| HW-465C Efficiency | ~90% | 12V boost |
| DD4012SA Efficiency | ~85% | 5V buck (typical at this load) |
| Combined Efficiency | ~77% | Total system |

### Battery Specifications

| Parameter | Value | Calculation |
|---|---|---|
| Cell Configuration | 1S2P | 2 cells in parallel |
| Cell Capacity | 3000mAh | Per cell |
| Total Capacity | 6000mAh | Parallel addition |
| Nominal Voltage | 3.7V | Single cell |
| Total Energy | 22.2Wh | 6000mAh × 3.7V |

### Runtime Estimate

```
Effective Energy = Total Energy × Efficiency
                  = 22.2Wh × 0.77
                  ≈ 17.1Wh

Runtime = Effective Energy / System Power
        = 17.1Wh / 3.1W
        ≈ 5.5 hours
```

**Estimated Runtime: 5 – 5.5 hours**

> ⚠️ **Note**: This is a conservative estimate. Actual runtime may vary based on:
> - Home Assistant Green processing load
> - Thread network activity
> - Battery age and condition
> - Temperature conditions
> - DD4012SA actual efficiency (76% – 90% depending on load and input voltage)

> 💡 **Tip**: The DD4012SA is most efficient at ~50–80% of its rated load. At the ~100 mA draw of the ESP32-H2 the efficiency is in the upper end of the 76–90% range, so real-world runtime is typically closer to 5.5 hours.

---

## Troubleshooting

### 1. ESP32-H2 Not Powering On
**Symptoms**: No LED indication, no serial output

**Possible Causes**:
- DD4012SA is wrong variant (not 5V)
- Polarity reversal
- Loose connections
- Insufficient input voltage to DD4012SA (needs ≥ 6.5V for 5V output)

**Solutions**:
1. Verify DD4012SA is the **5V** variant (check SKU / silkscreen)
2. Measure DD4012SA output with a multimeter (should read 5.0V ± 0.1V)
3. Check all power connections for correct polarity
4. Ensure 5V and GND are connected to correct pins
5. Try a different USB-C power supply (3.6A+)
6. Confirm HW-465C 12V rail is actually at 12V (DD4012SA needs ≥ 6.5V in)

### 2. Boot Loop on Power Restore
**Symptoms**: ESP32-H2 repeatedly reboots when mains power returns after battery cutoff

**Cause**: Voltage dip during HW-465C startup combined with Thread radio initialization

**Solution**:
- Add a **100µF to 220µF electrolytic capacitor** across the DD4012SA 5V output (Pin 3) and GND (Pin 2)
- This buffers voltage drops during startup

### 3. Erratic Mains Detection
**Symptoms**: Mains status randomly toggles during grid loss

**Possible Causes**:
- Ground continuity issue between modules
- HW-465C switching ground line
- Loose optocoupler connection

**Solution**:
1. Verify all GND connections are unified (DD4012SA, ESP32, HW-465C OUT-)
2. Check PC817 connections are secure
3. Ensure common ground reference is maintained

### 4. Incorrect Battery Readings
**Symptoms**: MAX17043 shows wrong voltage or -1%

**Critical Checks**:
| Issue | Solution |
|---|---|
| Wrong voltage | Verify CELL+ connected to Battery B+, NOT 12V rail |
| -1% reading | I2C communication error; check SDA/SCL connections |
| Jumps erratically | Check for intermittent connection |

### 5. DS18B20 Sensors Not Detected
**Symptoms**: Temperature sensors not appearing in Home Assistant

**Troubleshooting Steps**:
1. Verify 4.7kΩ pull-up resistor is connected between GPIO 5 and 3.3V
2. Check sensor wiring (VCC, GND, Data)
3. Ensure sensors are properly daisy-chained
4. Check ESPHome logs for 1-Wire device discovery

### 6. Thread Connection Issues
**Symptoms**: ESP32 not connecting to Thread network

**Possible Causes**:
- OTBR not operational
- Incorrect Thread dataset
- Network interference

**Solutions**:
1. Verify OTBR (SLZB-MR5U) is powered and functioning
2. Confirm Thread dataset is correct in secrets.yaml
3. Check signal strength sensor in Home Assistant
4. Ensure ESP32-H2 is within range of OTBR

### 7. Components Getting Hot
**Warning**: Excessive heat indicates a problem

| Hot Component | Likely Cause | Action |
|---|---|---|
| DD4012SA | Input over-voltage or short on output | Verify 12V input (must be ≤ 40V); check output for shorts |
| ESP32-H2 | Overvoltage (DD4012SA wrong variant) | Verify DD4012SA is the **5V** variant, output ≤ 5.1V |
| HW-465C | Overload | Reduce load or increase power supply |

> ✅ **Note on DD4012SA thermal behavior**: The DD4012SA has built-in **overtemperature protection (OTP)**. It will automatically shut down its output if it overheats, protecting itself and your ESP32. The HW-465C will resume output when the module cools.

> ⚠️ **STOP IMMEDIATELY** if any component becomes hot to touch. Disconnect power and investigate.

### 8. DD4012SA-Specific Issues

| Symptom | Likely Cause | Action |
|---|---|---|
| Output reads 0V | Input voltage below 6.5V (UVLO) | Check HW-465C output is actually 12V |
| Output reads 3.3V / 12V / other | Wrong SKU ordered | Replace with `DD4012SA_5V` variant |
| Output cuts off after a few seconds | Overtemperature shutdown | Improve airflow, reduce load |
| Output cuts off under load | Overcurrent protection | Check output is not shorted; load should be < 1A |
| Module gets warm (not hot) | Normal operation | No action needed — switching regulators dissipate some heat |

---

## Why DD4012SA Instead of Mini360?

A brief summary of the advantages of moving this project from the Mini360 to the DD4012SA:

| Concern | Mini360 | DD4012SA |
|---|---|---|
| Output voltage setting | User must adjust a tiny potentiometer with a screwdriver while measuring with a multimeter | **Factory preset by SKU** — no adjustment possible, no risk of over-voltage |
| Risk of killing ESP32-H2 | High if pot is mis-adjusted (e.g., 7V, 9V) | **Zero** — output is fixed to 5V by the factory |
| Built-in protections | None | **OTP, OCP, SCP, UVLO, BS-voltage** |
| Quiescent current | ~0.5–1 mA (typical for Mini360) | ~1.5 mA |
| Efficiency at light loads | 80–90% | 76–90% (similar in practice) |
| Max output current | 1.8–2 A | 1 A (still 10× the ESP32-H2 needs) |
| Form factor | Open PCB with screw terminal | Compact TO-220-style 3-pin module, **breadboard friendly** |
| Industrial-grade components | Consumer-grade | **Yes** (operating range −40 °C to +85 °C) |
| Assembly time for this project | ~5–10 min (adjust pot, verify with meter) | **< 1 min** (just plug it in) |

For a project where the 5V rail directly powers a microcontroller, the **factory-set output and built-in protections** of the DD4012SA are decisive advantages over the Mini360's adjustable-but-unprotected design.

---

## Future Modifications

### Adding/Removing Sensors
If you need to modify the sensor configuration:

1. **DS18B20 Sensors**: Update the `sensor:` block in the YAML
   - Use `index` for initial setup
   - Replace with `address` for permanent configuration

```yaml
sensor:
  - platform: dallas_temp
    address: 0x1234567890ABCD01  # Replace with actual address
    name: "Battery Cell 1 Temperature"
```

2. **I2C Sensors**: Add new I2C devices to the same bus
   - Ensure unique I2C addresses
   - Update ESPHome configuration

### Customizing Timestamps
Modify the `globals:` section in the YAML to:
- Change default threshold values
- Add additional event tracking
- Adjust polling intervals

### Network Configuration
For advanced Thread network configurations:
- Adjust `device_type` for different roles
- Modify `tx_power` for range optimization
- Configure channel preferences

---

## License

This project is provided as-is for educational and personal use.

---

## Contributing

Contributions are welcome! Please submit issues and pull requests through GitHub.

---

## Acknowledgments

- ESPHome community for the excellent firmware platform
- Home Assistant team for the smart home ecosystem
- OpenThread contributors for the Thread protocol implementation

---

**Version**: 1.2.1-alpha (Pre-Release Alpha) — *Polling and network-traffic correction*
**Last Updated**: October 2026

> **Note**: This is a pre-release alpha. While validated, it has not been extensively tested in all scenarios. Use in production systems at your own risk. Contributions and testing feedback are welcome.

See [CHANGELOG.md](CHANGELOG.md) for the full list of changes in this release.

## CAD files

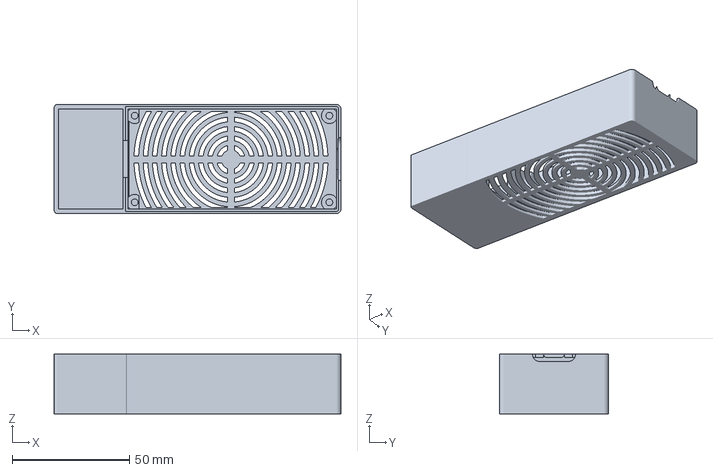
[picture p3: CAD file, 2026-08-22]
docs/ups_case_3d_print/ups_case_box_mod.3mf
122.5 x 46.6 x 25.5 mm

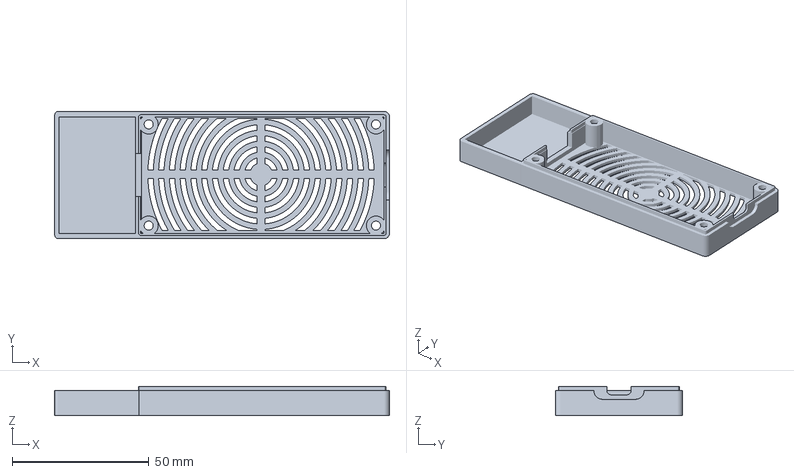
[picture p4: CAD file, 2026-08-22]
docs/ups_case_3d_print/ups_case_lid_mod.3mf
122.5 x 46.6 x 10.8 mm

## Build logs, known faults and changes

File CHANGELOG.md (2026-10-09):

# Changelog

All notable changes to this project will be documented in this file.

The format is based on [Keep a Changelog](https://keepachangelog.com/en/1.0.0/),
and this project adheres to [Semantic Versioning](https://semver.org/spec/v2.0.0.html).

---

## [1.2.1-alpha] - 2026-10-10

### Pre-Release Alpha — Polling and Network-Traffic Correction

No change to the mains-detection logic or event semantics introduced in `1.2.0-alpha`. This release corrects
**how often values are read and transmitted over Thread**, plus one runtime defect found by compiling.

Validated against ESPHome **2026.9.1** (`esphome config` → `Configuration is valid!`) and **compiled
successfully** against ESP-IDF 5.5.5 — flash 41.0 %, RAM 37.7 %.

#### Fixed

- **Malformed log format string in the critical-battery handler — found by a real compile log.**
  - `ESP_LOGI("battery", "Critical 3% battery threshold ...")` — the bare `%` followed by a space is parsed
    by GCC as the printf *space flag* applied to a `%b` conversion, a GNU binary format that expects an
    `unsigned int` argument. No such argument was ever supplied.
  - The compiler warned: `' ' flag used with '%b' gnu_printf format` and
    `format '%b' expects a matching 'unsigned int' argument`.
  - At runtime this is undefined behaviour. The real output was
    `Critical 3101011001011001011100100011000attery threshold reached during outage.` — the `3` and the
    following space were consumed, replaced by uninitialised register contents rendered in binary. It
    corrupted the one log line that matters most during a genuine low-battery event.
  - The percent is now escaped as `%%`. Verified against GCC: the warning is gone and the line prints
    `Critical 3% battery threshold reached during outage.`
  - This is exactly the class of defect that schema validation cannot catch — it only appears in a full
    compile.

- **`openthread_info` was polling far faster than documented — by a wide margin the largest source of
  network traffic on this device.**
  - ESPHome's defaults for this platform are aggressive: `parent_last_rssi` polls every **5 s**, and
    `role` / `ip_address` / `channel` every **1 s**.
  - Those four entities alone accounted for roughly **11,500 messages per hour** across the Thread link.
  - Previous documentation stated these polled at 60 s. That was incorrect and is now corrected throughout.
  - All four are now set to **900 s**.
- **The timestamp and status text sensors re-sent identical values every 60 s.**
  - `TemplateTextSensor` is a `PollingComponent` with a 60 s default, so `Time sync`, `Last Power Outage
    Time`, `Last Mains Restore Time`, `Last Low Battery 3% Time` and `Last Reboot Time` polled
    continuously — on top of being published explicitly by the mains-detection and time-sync handlers.
  - They now use `update_interval: never`, with the restored NVS values published once from `on_boot` so
    Home Assistant does not show `unknown` until the first mains event.

#### Added

- **`delta` filters on the battery and temperature sensors.**
  - ESPHome publishes a sensor's state on **every** poll, even when the value is unchanged
    (`Sensor::publish_state()` calls the frontend unconditionally). `force_update` only affects whether
    Home Assistant *records* the value — not whether the message is transmitted.
  - Filters now suppress unchanged readings before transmission:
    cell temperature `delta: 0.5` °C, battery level `delta: 1` %, battery voltage `delta: 0.05` V.
  - The sensor is still **read** every poll — a local I²C / 1-Wire transaction — so detection latency is
    unaffected. Only the network send is suppressed.
- **The *Sensor Update Interval* control now also governs both DS18B20 cell sensors**, and its range is
  widened from 10–120 s to **10–300 s** (10 s steps).

#### Changed

- **DS18B20 cadence raised from 10 s to the slider value (30 s default).**
  - Deliberately **not** slowed further. An 18650 has roughly 40 J/K of thermal capacity, so a developing
    internal fault raises its temperature by about 15 °C/min at 10 W and 30 °C/min at 20 W. A 300 s
    interval would miss most of such an event — at 10 W the cell gains ~75 °C between two samples.
  - The delta filter is what makes the fast cadence affordable, rather than a slow read interval.
- **The 3 % critical-battery check moved from `on_value` to `on_raw_value`.**
  - `on_value` fires only when a value passes the filter chain, so with a `delta: 1` filter in place the
    safety threshold would only be evaluated on transmissions.
  - `on_raw_value` is evaluated on **every** reading regardless of whether the filter suppressed the send,
  keeping the low-battery event detection independent of the reporting cadence.

#### Projected network traffic

At the 30 s default, estimated messages per hour fall from roughly **12,800** to **~40–90**, depending on how
fast the values actually move (they move faster during an active discharge). That is a reduction of well over
**99 %**, while worst-case detection latency for a thermal or low-battery event stays at one poll.

The pre-change figure counts every publish, including unchanged readings: 120 (battery level) + 120 (voltage)
+ 360 + 360 (cell temperatures) + 720 (RSSI) + 3,600 × 3 (role, IP, channel) + 300 (five template text
sensors).

#### Upgrade notes

- Existing entities keep their IDs, so Home Assistant will re-pair by name without losing history.
- Home Assistant may briefly show the five timestamp entities as `unknown` until first boot after upgrade;
  they are published once from `on_boot`.
- Statistics and long-term graphs remain correct — the delta filter changes *when* a value is reported, not
  its accuracy.

---

## [1.2.0-alpha] - 2026-10-10

### Pre-Release Alpha — Firmware Correctness & Documentation

> **Warning**: This is a pre-release alpha. The configuration was validated against ESPHome **2026.9.1**
> (`esphome config` → `Configuration is valid!`), but hardware behaviour has not been exhaustively tested.
> Use in production systems at your own risk.

> ⚠️ **Upgrade notice**: v1.1a recorded mains-event timestamps against the **wrong edge** of the detection
> signal. Historical `Last Power Outage Time` / `Last Mains Restore Time` values stored before this release
> are swapped and cannot be corrected retroactively.

### Fixed

- **Mains detection triggers were inverted (`binary_sensor.on_press` / `on_release`)**
  - The PC817 optocoupler pulls GPIO4 LOW while mains is present. With `inverted: true`, LOW maps to a
    logical `true`, so `on_press` fires on **mains restored** and `on_release` on **mains lost**.
  - The handlers were the other way round: the outage timestamp was written when power *arrived*, and the
    restore timestamp when power *left*.
  - Both handlers are now swapped. Confirmed against `esphome/core/automation.h`, where `on_press` is bound
    to `TriggerOnTrueForwarder` and `on_release` to `TriggerOnFalseForwarder`.
  - Side effect fixed: `low_bat_logged` is now reset when mains is restored rather than when it is lost, so
    the 3 % critical-battery event logs correctly on each subsequent outage.
- **Mains-restored timestamp could be recorded as `1970-01-01`**
  - The restore handler called `strftime()` without first checking `current_time.now().is_valid()`.
  - On an unsynced clock it stored a bogus epoch value as a real event time.
  - It now writes `Time Sync Pending`, matching the behaviour already present in the outage handler.
- **`sensor:` update-interval number was inert**
  - `update_interval_slider` was declared and advertised in the README but referenced by no component.
  - See *Added* below for the wiring.

### Added

- **Runtime update-interval control**
  - Added `id: ups_fuel_gauge` to the MAX17043 platform so the polling loop can be retuned at runtime.
  - Wired `set_action` on the *Sensor Update Interval* template number to `set_update_interval()`.
  - Added an `on_boot` hook (priority `-100`) so the NVS-restored value is re-applied after every reboot.
  - Previously the entity changed nothing at runtime.
- **`safe_mode` boot-loop guard**
  - `boot_is_good_after: 2min`, `num_attempts: 10`, `reboot_timeout: 5min`.
  - Addresses the long-standing "Boot Loop on Power Restore" known issue by falling back to the last
    known-good firmware after repeated failed boots.
  - Added as a **top-level component** — `ota: - platform: safe_mode` is *not* valid; `safe_mode` is a
    standalone component that `ota:` auto-loads.
- **Documentation**
  - Added a minimum-version requirement table explaining why each floor matters:
    - ESPHome **2026.9.1** (validated against) — `openthread_info` sensor/text_sensor platforms
    - ESPHome **2025.11.0** — `dallas_temp` regained the `index:` option (removed in 2024.6, restored 2025.11)
    - ESPHome **2025.6.0** — the `openthread` component was introduced
  - Documented that `on_press` / `on_release` are *logical state* triggers, not physical pin edges.
  - Documented that ESPHome's built-in `SDA`/`SCL` aliases resolve to GPIO21/GPIO22 on every ESP32
    variant — including the H2, where GPIO21 is a SPI-flash pin. Explicit `sda:`/`scl:` are mandatory.
  - Added a DS18B20 addressing section noting `index:` is 0-based and order-dependent.
  - Added a "What's New in v1.2.0-alpha" section to the README.

### Changed

- **Documented `openthread: tlv:` as correct, with an explicit warning.**
  - A third-party review recommended renaming `tlv:` to `network_dataset:`. That key does not exist;
    applying it breaks the build with
    `[network_dataset] is an invalid option for [openthread]`.
  - The real key is `CONF_TLV = "tlv"` (`esphome/components/openthread/const.py`). The value is a
    hex-encoded operational dataset TLV, **not** a file path.
  - Added inline comments in the YAML plus README warnings so this is not "corrected" again.
- Version scheme standardised to `1.2.0-alpha` (was `1.1a` / `1.0a`) so the tag parses as valid SemVer and
  GitHub's pre-release UI recognises it.

### Documentation Fixes

- **Thread dataset example in `secrets.yaml` was invalid.** The sample had an odd number of hex characters
  and embedded prose, so copying it verbatim failed validation with
  `TLV must have an even number of hex characters`. Replaced with a single quoted line of valid hex plus
  an explicit warning and a key-generation command.
- **Runtime claim corrected.** The title said "Up To 6 Hours Runtime" while the calculation and changelog
  both conclude 5–5.5 hours. Title now reads **5.5 Hours**.
- **Power-pin locations corrected.** The README stated 5V/GND were on the top *left* and 3V3 on the top
  *right*. Board photo inspection confirms **5V, GND and 3V3 are all on the top right**, contiguous as one
  3-pin header, with no power pin on the left column. Corrected in the pin tables, wiring steps 4.4 / 8.2
  and the ASCII pinout diagram; added a note about the unused `BAT` pad.
- **Broken filename reference.** `hag_smart_ups_for_esphome.yaml` → `hag_smart_ups.yaml`.
- **Non-existent protection removed.** The features table advertised OVP for the DD4012SA; its actual
  protections are OTP, OCP, SCP, UVLO and BS-voltage. Corrected to UVLO/OCP/SCP/OTP.
- **False persistence claim removed.** The *Time Sync* text sensor was documented as "Survives reboot",
  but `saved_time_sync_status` has `restore_value: no`. Now reads "Resets on reboot".
- **Dead entity documented honestly.** The *Sensor Update Interval* control is no longer listed as
  "Fixed"-interval elsewhere in the doc.
- **Garbled trailing text removed** — a stray `stems at your own risk. Contributions and testing feedback
  are welcome.` line at the end of the README.
- **Copyright attribution unified.** The changelog footer said "HAG Smart UPS Contributors" while `LICENSE`
  said "Legolas-2025". The changelog now matches the LICENSE.
- Softened the "100% interchangeable" claim for PC817/EL817 to a drop-in replacement with a CTR caveat.
- Replaced the non-portable CHANGELOG anchor links with plain-text version names.

### Known Issues

- DS18B20 sensors are addressed by `index:` (probe order), which can change if sensors are swapped.
  **Workaround**: record the hex addresses ESPHome prints on first boot and switch both entries to `address:`.
- Boot loop may still occur when mains power restores after battery cutoff.
  **Workaround**: fit a 100 µF – 220 µF electrolytic across the DD4012SA 5V output (pin 3) and GND (pin 2).
  The new `safe_mode` block limits the damage but does not prevent the underlying brown-out.

### Security Considerations

- API encryption key must be generated per device and stored in `secrets.yaml`; do not commit it.
- Thread network datasets contain the network key and must be kept out of public repositories.
- The README ships an **illustrative placeholder** dataset and key — generate your own before deploying.

---

## [1.1a] - 2026-09-04

### Pre-Release Alpha — DD4012SA Migration

> **Warning**: This is an alpha release. The software is functional but has not been extensively tested in all scenarios. Use in production systems at your own risk.

> ⚠️ **Superseded**: see [1.2.0-alpha](#120-alpha---2026-10-10) — the mains-detection triggers in this
> release are inverted.

### Changed

- **Power Stage: Mini360 → DD4012SA**
  - Replaced the Mini360 adjustable buck converter with the **DD4012SA** factory-set buck converter (5V variant)
  - **Removed** all Mini360 references, including potentiometer adjustment procedures and "adjust-while-measuring" steps
  - The 5V rail is now generated by a TO-220-compatible DD4012SA module with breadboard-friendly 2.54 mm pin pitch
  - The DD4012SA accepts the 12V HW-465C rail directly (6.5V – 40V input range) and outputs a fixed 5.0V with no user adjustment
- **Bill of Materials**
  - Replaced the Mini360 entry with **DD4012SA Buck Converter (5V variant)** — `DD4012SA_5V`
  - Updated all related component notes to reference the DD4012SA
- **Wiring and Schematics**
  - Updated the System Architecture Overview, Detailed Wiring Schematic, ESP32-H2 Wiring Detail, and Sensor Wiring Detail to show the DD4012SA in place of the Mini360
  - DD4012SA pin labels (`IN+`, `GND`, `OUT+`) are now used consistently across all diagrams
  - The wiring guide no longer requires any potentiometer-tuning step
- **Estimated Runtime**
  - DD4012SA efficiency assumed at **~85%** (typical for ~100 mA load from 12V input)
  - Combined system efficiency updated to **~77%**
  - Runtime estimate revised to **5 – 5.5 hours** (up from the Mini360-based figure)
- **Troubleshooting**
  - Added a new **"DD4012SA-Specific Issues"** section covering UVLO, OCP, OTP, and wrong-SKU symptoms
  - Updated the **"Components Getting Hot"** table to describe DD4012SA thermal behavior
  - Updated the **"Boot Loop on Power Restore"** workaround to reference the DD4012SA 5V output instead of the Mini360
- **Documentation**
  - Added a new **"DD4012SA Buck Converter - Detailed Specifications"** section with full electrical, mechanical, and thermal specs
  - Added a new **"Why DD4012SA Instead of Mini360?"** section comparing the two regulators across nine key concerns
  - Updated the README version line from `1.0a` to **`1.1a (Pre-Release Alpha) — DD4012SA migration`**
  - Updated **"Last Updated"** to September 2026

### Added

- **DD4012SA Reference Material**
  - DD4012SA configuration table (5V variant specs)
  - Built-in protections table: OTP, OCP, SCP, UVLO, BS-voltage
  - DD4012SA pinout diagram (3 pins: `IN+`, `GND`, `OUT+`)
  - Pin connections table mapping DD4012SA pins to HW-465C and ESP32-H2
  - Optional 100 µF – 220 µF output-stabilization capacitor recommendation
- **Bench-Test Procedure (Optional)**
  - Step-by-step instructions to verify the 5V output with a multimeter before connecting to the ESP32-H2
- **Phase 2: Prepare the DD4012SA Buck Converter**
  - SKU verification checklist (3.3V, 5V, 12V variants)
  - Removed the "adjust potentiometer" step that existed for the Mini360

### Removed

- All references to the **Mini360** buck converter
- All references to the Mini360 **potentiometer** and its adjustment procedure
- "Adjust potentiometer while measuring with multimeter" assembly step
- Mini360-specific troubleshooting entries

### Known Issues

- Boot loop may still occur when mains power restores after battery cutoff
  - **Workaround**: Add a 100 µF – 220 µF electrolytic capacitor across the **DD4012SA** 5V output (Pin 3) and GND (Pin 2)
- DS18B20 sensor addressing requires manual configuration after initial boot
  - **Workaround**: Use index-based addressing initially, then replace with address-based configuration after identifying sensor IDs

### Security Considerations

- API encryption key must be configured in `secrets.yaml` before deployment
- Thread network dataset should be kept secure and not shared publicly
- Default configurations are not suitable for production without proper key management

---

## [1.0a] - 2026-08-21

### Pre-Release Alpha

> **Warning**: This is an alpha release. The software is functional but has not been extensively tested in all scenarios. Use in production systems at your own risk.

### Added

- **Core UPS Monitoring**
  - Real-time battery level monitoring via MAX17043 I2C fuel gauge
  - Battery voltage sensing with configurable thresholds
  - Dual DS18B20 temperature sensors for battery cell monitoring
  - Mains power status detection using PC817 optocoupler
- **Thread Network Integration**
  - OpenThread protocol support for wireless connectivity
  - ESP32-H2 as Minimal Thread Device (MTD)
  - Thread network diagnostics (signal strength, device role, IP address, channel)
  - Seamless integration with SLZB-MR5U and compatible OTBR hardware
- **Smart Features**
  - Persistent event logging with NVS-backed timestamps
  - Automatic power outage detection and timestamp recording
  - Low battery event logging (3% threshold during outage)
  - Intelligent time synchronization with auto-retry mechanism (up to 4.5 minutes)
  - Configurable sensor update intervals (10s - 120s)
- **Home Assistant Integration**
  - Native ESPHome API with encrypted communication
  - Push-based entity updates for instant state changes
  - Remote device restart capability
  - Comprehensive set of exposed entities:
    - 5 sensors (battery level, voltage, 2x temperature, signal strength)
    - 1 binary sensor (mains power status)
    - 5 text sensors (time sync, outage logs, reboot time)
    - 1 button (restart)
    - 1 number control (update interval slider)
- **Hardware Protection**
  - Hardware cutoff design for automatic recovery
  - Deep discharge prevention via HW-465C module
  - Battery cell temperature monitoring for thermal protection
- **Documentation**
  - Comprehensive step-by-step assembly guide
  - Detailed wiring schematics and pinout references
  - Troubleshooting section for common issues
  - Estimated runtime calculations for various battery configurations

### Known Issues

- Boot loop may still occur when mains power restores after battery cutoff
  - **Workaround**: Add 100µF - 220µF electrolytic capacitor across Mini360 5V and GND terminals
- DS18B20 sensor addressing requires manual configuration after initial boot
  - **Workaround**: Use index-based addressing initially, then replace with address-based configuration after identifying sensor IDs

### Security Considerations

- API encryption key must be configured in secrets.yaml before deployment
- Thread network dataset should be kept secure and not shared publicly
- Default configurations are not suitable for production without proper key management

---

## [Unreleased] - Future Releases

### Potential Future Features

- [ ] Support for additional battery configurations (2S, 3S)
- [ ] Configurable low battery threshold
- [ ] Energy consumption statistics
- [ ] Integration with Home Assistant Energy Dashboard
- [ ] MQTT support for non-Thread deployments
- [ ] Over-the-air (OTA) firmware update improvements
- [ ] Web UI for configuration without Home Assistant
- [ ] Persist `low_bat_logged` across reboots so a mid-outage reboot cannot re-fire the 3 % event

### Potential Enhancements

- [ ] Email/push notifications for critical events
- [ ] Historical data logging and visualization
- [ ] Support for multiple battery packs
- [ ] Solar panel input monitoring
- [ ] Expansion GPIO pins for additional sensors

---

## Version History

| Version | Type | Date | Status |
|---|---|---|---|
| 1.2.1-alpha | Pre-Release Alpha | 2026-10-10 | **Current** |
| 1.2.0-alpha | Pre-Release Alpha | 2026-10-10 | Superseded |
| 1.1a | Pre-Release Alpha | 2026-09-04 | Superseded — mains triggers inverted |
| 1.0a | Pre-Release Alpha | 2026-08-21 | Superseded |

---

## Contributing

If you find bugs or have suggestions for improvements, please:

1. Open an issue on GitHub with detailed reproduction steps
2. Submit pull requests with clear descriptions of changes
3. Test on various hardware configurations when possible

For major changes, please open an issue first to discuss the proposed modifications.

---

## License

This project is released under the MIT License. See the [LICENSE](LICENSE) file for details.

Copyright (c) 2026 Legolas-2025

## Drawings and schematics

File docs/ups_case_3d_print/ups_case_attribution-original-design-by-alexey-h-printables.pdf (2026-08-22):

## 18650 router onu ups case

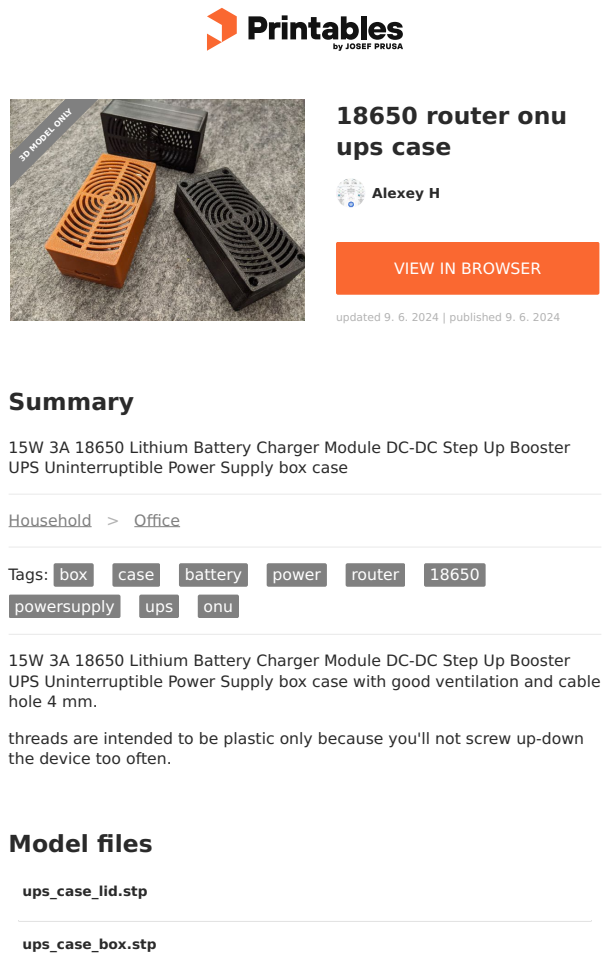
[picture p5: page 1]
Model files; Summary; Household > Office; Tags: box; case; battery; power; router; powersupply; ups; onu; Alexey H; updated 9. 6. 2024 | published 9. 6. 2024; ups_case_lid.stp; ups_case_box.stp; 3D MODEL ONLY

VIEW IN BROWSER (https://printables.com/model/906875-18650-router-onu-ups-case)

15W 3A 18650 Lithium Battery Charger Module DC-DC Step Up Booster
UPS Uninterruptible Power Supply box case

UPS Uninterruptible Power Supply box case with good ventilation and cable
hole 4 mm.

threads are intended to be plastic only because you'll not screw up-down
the device too often.

## License

This work is licensed under a
Creative Commons (4.0 International License)

Attribution-NonCommercial (http://creativecommons.org/licenses/by-nc/4.0/)

✖ | Sharing without ATTRIBUTION
✔ | Remix Culture allowed
✖ | Commercial Use
✖ | Free Cultural Works
✖ | Meets Open Definition

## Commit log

2026-08-22 3D Printable UPS Case
    This is a modification of an original case design by Alexey H, pupblished on Printables.com under Creative Commons (4.0 International License).
    For more info see the attached "ups_case_attribution-original-design-by-alexey-h-printables.pdf" file.
    [ups_case_box_mod.3mf, ups_case_lid_mod.3mf]
2026-09-03 v1.1a Update - replace Mini360 with DD4012SA Buck Converter
    DD4012SA Advantages:
    1. No potentiometer adjustment needed — output is factory-preset by SKU (DD4012SA_5V), eliminating the entire "adjust pot with multimeter" step and the risk of accidentally sending 7V/9V to the ESP32-H2.
    2. Built-in protections added: OTP (overtemperature), OCP (overcurrent), SCP (short circuit), UVLO (input under-voltage lockout), and BS-voltage protection
    3. Industrial-grade components operating from −40 °C to +85 °C
2026-09-03 Update CHANGELOG for version 1.1a changes
    Updated CHANGELOG to reflect changes in version 1.1a, including migration from Mini360 to DD4012SA buck converter, new features, and known issues.
2026-10-07 v1.2.0-alpha - Refactor ESPHome configuration and improve logging
    Updated comments and fixed logging messages in the ESPHome configuration for HAG Smart UPS Monitor. Adjusted the dataset configuration and removed unused sensor update interval settings.
2026-10-07 Revert v1.2.0-alpha changes — restore to v1.1a state (2026-09-03)
2026-10-09 Release 1.2.1-alpha: Fix polling and network traffic
    This release corrects polling frequency and network traffic issues, improves logging, and adds delta filters for sensors. It also updates the documentation to reflect accurate polling intervals and reduces network message frequency significantly.
2026-10-09 Revise README for v1.2.1-alpha updates
    Updated the README to reflect changes in version 1.2.1-alpha, including modifications to polling behavior and sensor update intervals.
2026-10-11 Update CHANGELOG for version 1.3.0-alpha
    Added new features for recorder protection and battery alerts, including a UPS Critical Battery Alert sensor and local thermal interlock. Updated version history to reflect the new release.
2026-10-11 Update README for v1.3.0-alpha features
    Added new features for UPS critical battery alert and recorder protection. Updated ESPHome configuration and pin safety audit.
